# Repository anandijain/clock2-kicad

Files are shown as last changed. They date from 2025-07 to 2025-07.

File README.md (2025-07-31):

# clock2-kicad

the ben eater clock module as a pcb
Schematic
PCB
3D

I'm not sure why the placement of the resistors, caps, and 555s (and a few other things) is wrong in the 3D file.

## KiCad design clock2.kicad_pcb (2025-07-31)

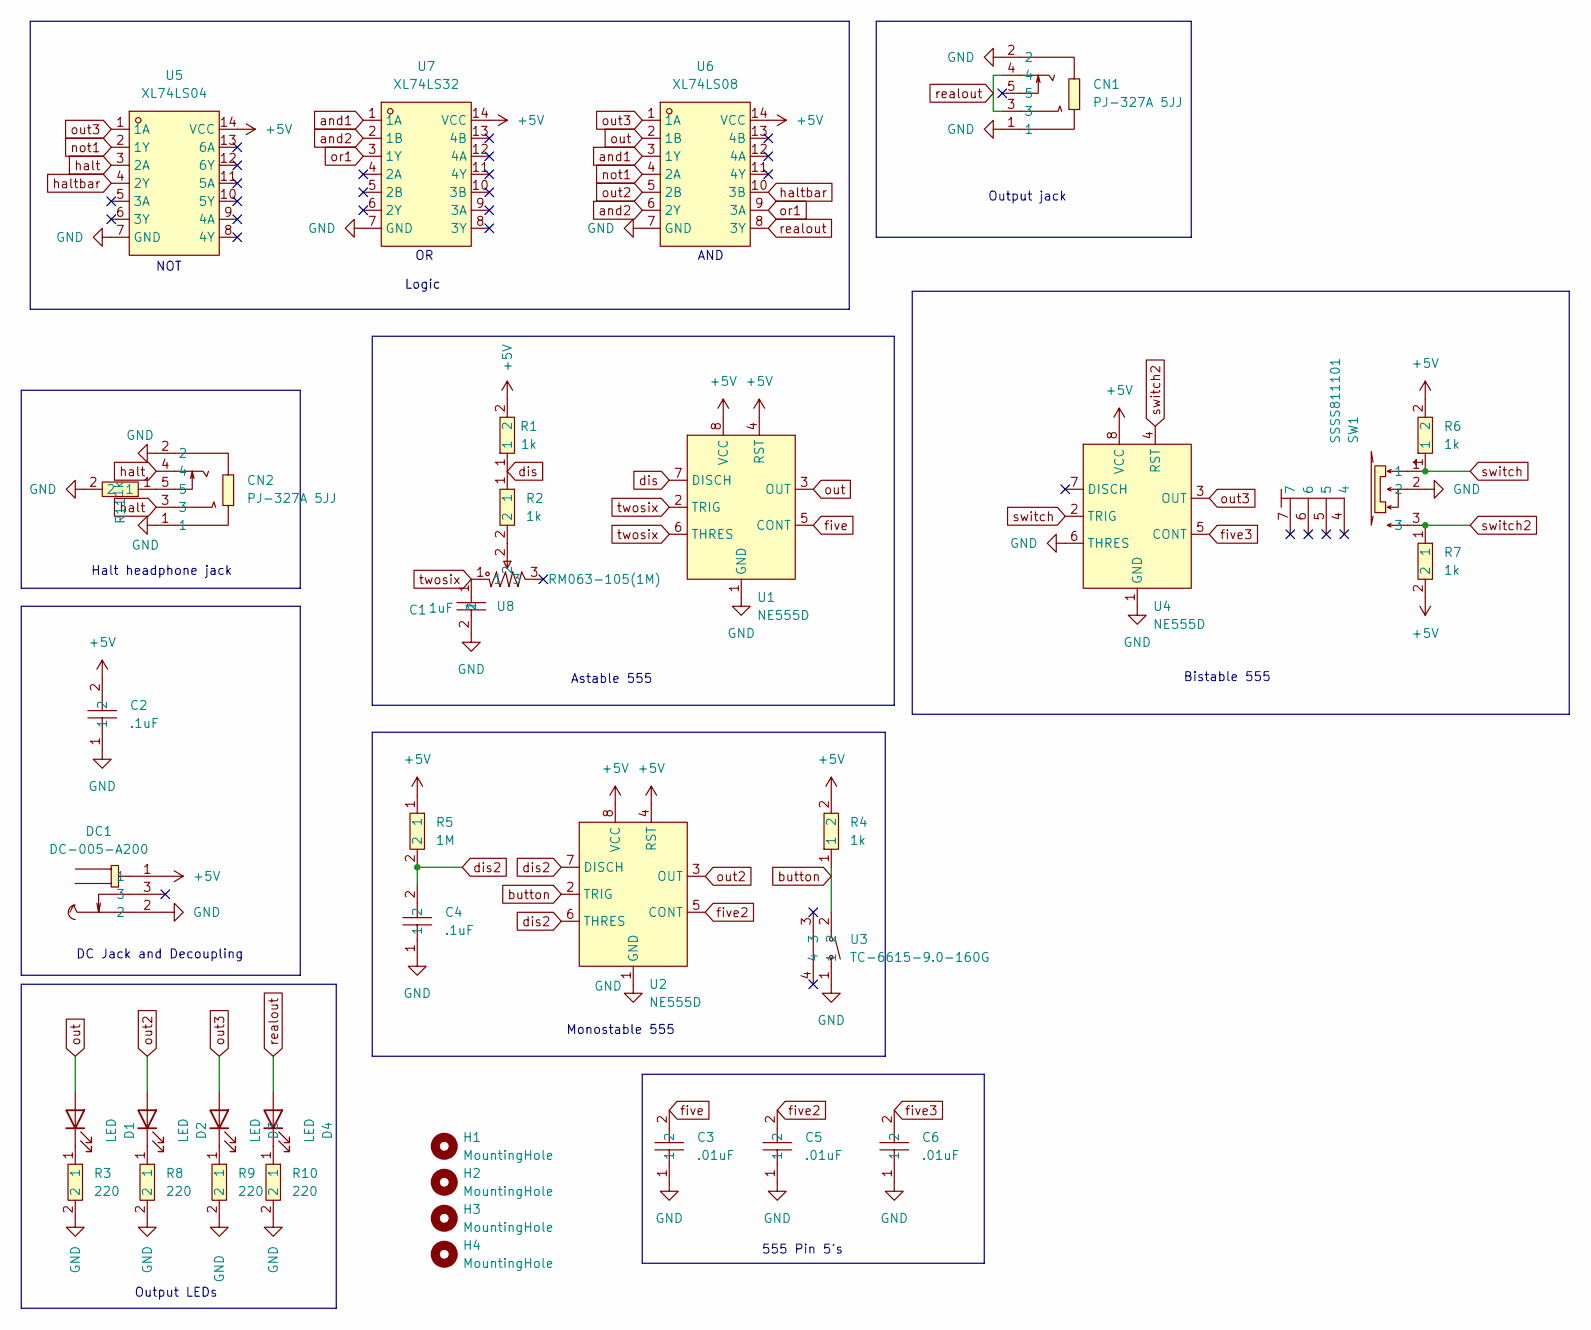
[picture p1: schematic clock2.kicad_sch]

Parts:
C1: 1uF; C0805; LCSC Part C28323
C2, C4: .1uF; C0805; LCSC Part C49678
C3, C5, C6: .01uF; C0805; LCSC Part C83170
CN1, CN2: PJ-327A 5JJ; AUDIO-SMD_PJ-327A5JJ; LCSC Part C668605
D1, D2, D3, D4: LED; LED_D5.0mm
DC1: DC-005-A200; DC-IN-TH_DC-005-A200; LCSC Part C720557
H1, H2, H3, H4: MountingHole; MountingHole_3.2mm_M3
R1, R2, R4, R6, R7, R11: 1k; R0805; LCSC Part C95781
R3, R8, R9, R10: 220; R0805; LCSC Part C17557
R5: 1M; R0805; LCSC Part C107700
SW1: SSSS811101; SW-SMD_SSSS811101; LCSC Part C109335
U1, U2, U4: NE555D; SOIC-8_L4.9-W3.9-P1.27-LS6.0-BL; LCSC Part C7593
U3: TC-6615-9.0-160G; KEY-TH_PTS645VXX83XLFS; LCSC Part C6575016
U5: XL74LS04; SOP-14_L8.6-W3.9-P1.27-LS6.0-BL; LCSC Part C513511
U6: XL74LS08; SOP-14_L8.6-W3.9-P1.27-LS6.0-BL; LCSC Part C521140
U7: XL74LS32; SOP-14_L8.6-W3.9-P1.27-LS6.0-BL; LCSC Part C521171
U8: RM063-105(1M); RES-ADJ-TH_RM063-103; LCSC Part C5205038

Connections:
+5V: C2.2, DC1.1, R1.2, R4.2, R5.1, R6.2, R7.2, U1.4 (RST), U1.8 (VCC), U2.4 (RST), U2.8 (VCC), U4.8 (VCC), U5.14 (VCC), U6.14 (VCC), U7.14 (VCC)
GND: C1.2, C2.1, C3.1, C4.1, C5.1, C6.1, CN1.1, CN1.2, CN2.1, CN2.2, DC1.2, R3.2, R8.2, R9.2, R10.2, R11.2, SW1.2, U1.1 (GND), U2.1 (GND), U3.1, U4.1 (GND), U4.6 (THRES), U5.7 (GND), U6.7 (GND), U7.7 (GND)
unnamed: CN2.5, R11.1
unnamed: D1.1 (K), R3.1
unnamed: D2.1 (K), R8.1
unnamed: D3.1 (K), R9.1
unnamed: D4.1 (K), R10.1
unnamed: R2.2, U8.2
and1: U6.3 (1Y), U7.1 (1A)
and2: U6.6 (2Y), U7.2 (1B)
button: R4.1, U2.2 (TRIG), U3.2
dis: R1.1, R2.1, U1.7 (DISCH)
dis2: C4.2, R5.2, U2.6 (THRES), U2.7 (DISCH)
five: C3.2, U1.5 (CONT)
five2: C5.2, U2.5 (CONT)
five3: C6.2, U4.5 (CONT)
halt: CN2.3, CN2.4, U5.3 (2A)
haltbar: U5.4 (2Y), U6.10 (3B)
not1: U5.2 (1Y), U6.4 (2A)
or1: U6.9 (3A), U7.3 (1Y)
out: D1.2 (A), U1.3 (OUT), U6.2 (1B)
out2: D2.2 (A), U2.3 (OUT), U6.5 (2B)
out3: D3.2 (A), U4.3 (OUT), U5.1 (1A), U6.1 (1A)
realout: CN1.3, CN1.4, D4.2 (A), U6.8 (3Y)
switch: R6.1, SW1.1, U4.2 (TRIG)
switch2: R7.1, SW1.3, U4.4 (RST)
twosix: C1.1, U1.2 (TRIG), U1.6 (THRES), U8.1

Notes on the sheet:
Output LEDs
Bistable 555
Monostable 555
Output jack
Halt headphone jack
DC Jack and Decoupling
AND
NOT
555 Pin 5's
Logic
Astable 555

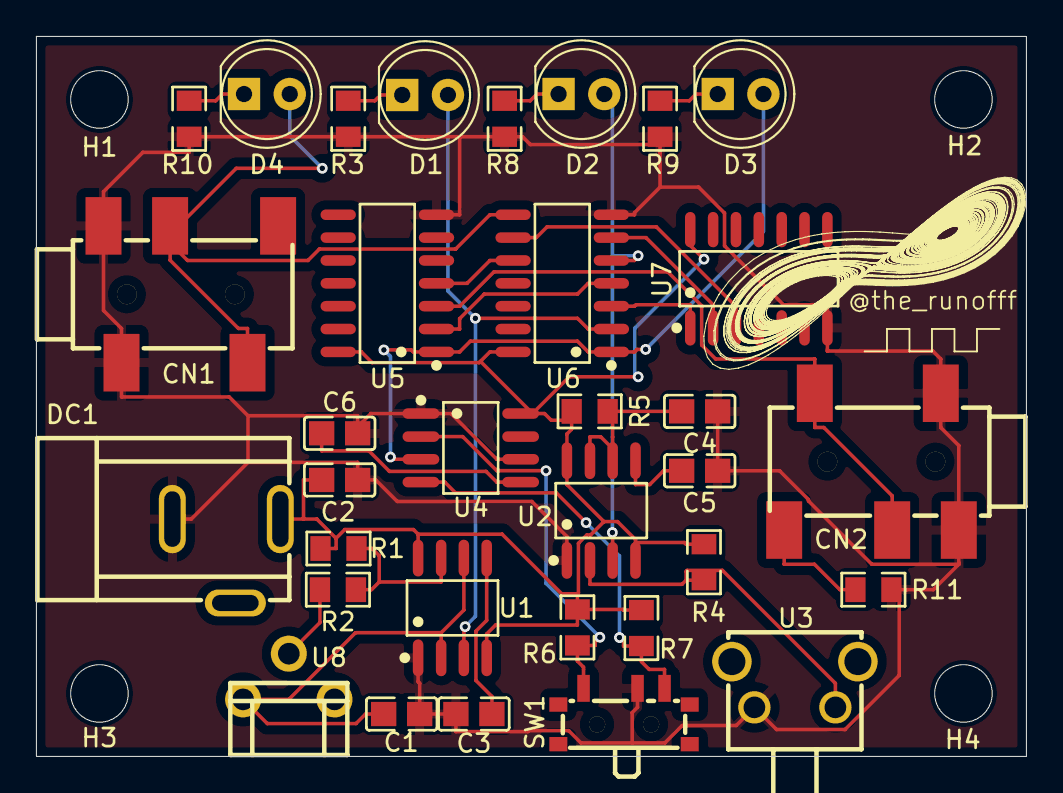
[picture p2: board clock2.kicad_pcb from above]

Board: 2 copper layers, 55.0 x 40.0 mm, 37 parts (0 on the bottom side), 27 nets.

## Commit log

2025-07-30 use the switching capability of the headphone jack to default the HALT signal to LOW. use resistor to prevent input HALT short to ground before contact breaks
    [clock2.kicad_pcb, clock2.kicad_sch]
2025-07-30 v1 finalized
    [clock2.kicad_pcb, clock2.kicad_sch]
2025-07-31 images in readme
    [clock2.kicad_pcb]
